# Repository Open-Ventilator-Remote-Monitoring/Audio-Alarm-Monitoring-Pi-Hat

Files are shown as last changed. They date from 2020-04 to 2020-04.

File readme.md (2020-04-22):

## Audio Alarm Monitoring Raspberry Pi Hat
### Overview
This add-on circuit board (Pi Hat) provides a 2.5mm audio input jack to allow a Soundear audio monitoring device to interface with a raspberry pi configured to work with the [Open Ventilator Remote Monitoring Software](https://github.com/Open-Ventilator-Remote-Monitoring/remote-ventilator-monitor-pi). An indicator LED is illuminated when a 5V digital signal is received from the Soundear audio monitor. This PCB contains a voltage divider circuit which reduces the 5V digital output from the soundear monitor to 3.3v digital logic suitable for the raspberry pi.

### Inputs & Outputs
#### Inputs
* 2.5mm audio jack from cable connected to soundear (5V digital input)
* 5V power from raspberry pi
* Ground on raspberry pi

#### Outputs
* GPIO 4 pin on raspberry pi (3.3V digital output)

#### Bill Of Materials
The Bill of Materials is in the [Audio Alarm Monitoring Pi Hat.csv](https://github.com/Open-Ventilator-Remote-Monitoring/Audio-Alarm-Monitoring-Pi-Hat/blob/master/Audio%20Alarm%20Monitoring%20Pi%20Hat.csv) file

#### Manufacturing Notes
* This board has slotted holes for all the J1 pads. 
* Milling data is in Audio Alarm Monitoring Pi Hat.GML

#### Assembly Notes
* XA1 is an optional connector for an external LED. Do not populate D1 if you plan to use it.
* This hat connects to a Raspberry Pi using two 10mm tall standoffs. A third 10mm standoff can be connected to the hat and will sit ontop of the Raspberry Pi to add additional support.

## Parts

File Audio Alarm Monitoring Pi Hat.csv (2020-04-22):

Part | Quantity | Value | Package | MFG Part Number | Link | Note | Library | Position | (mil) | Orientation
D1 | 1 |  | 1206 | QTLP651C4TR | https://www.digikey.com/product-detail/en/everlight-electronics-co-ltd/QTLP651C4TR/1080-1484-1-ND/7598723 | This or any other 1206 Green LED | SparkFun-LED | (375 825) |  | R0
J1 | 1 |  |  | 35RAPC4BHN2 | https://www.digikey.com/products/en?keywords=SC1459-ND |  | 35RAPC4BHN2 | (220 1712 | .59843) | R270
J2 | 1 |  | 2X6 FEMALE | BCS-106-L-D-TE | https://www.digikey.com/product-detail/en/samtec-inc/BCS-106-L-D-TE/SAM1008-06-ND/1100265 | This or any other 2x6 .1” connector | SparkFun-Connectors | -329.5275 | 6 2705.90551) | R0
Q1 | 1 |  | SOT-23 | MMSS8050-L-TP | https://www.digikey.com/product-detail/en/micro-commercial-co/MMSS8050-L-TP/MMSS8050-L-TPMSCT-ND/2827203 |  | SMD-TRANSISTORS-NPN-25V-500MW_SOT-23_ | (400 1025 | ) | R180
R1 | 1 | 2.2k | 1206 | CRG1206F2K2 | https://www.digikey.com/product-detail/en/te-connectivity-passive-product/CRG1206F2K2/A106075CT-ND/3477730 | This or any other 1206 resistor | SparkFun-Passives | (350 2450 | ) | R270
R2 | 1 | 3.3k | 1206 | CRG1206F3K3 | https://www.digikey.com/product-detail/en/te-connectivity-passive-product/CRG1206F3K3/A106076CT-ND/3477732 | This or any other 1206 resistor | SparkFun-Passives | (500 2450 | ) | R90
R3 | 1 | 4.7k | 1206 | CRG1206F4K7 | https://www.digikey.com/product-detail/en/te-connectivity-passive-product/CRG1206F4K7/A106078CT-ND/3477735 | This or any other 1206 resistor | SparkFun-Passives | (450 1250 | ) | R270
R4 | 1 | 150 | 1206 | RC1206FR-07150RL | https://www.digikey.com/product-detail/en/yageo/RC1206FR-07150RL/311-150FRCT-ND/731508 | This or any other 1206 resistor | SparkFun-Passives | (300 1250 | ) | R90
XA1 | 1 |  | XHP-2 | B2B-XH-A-GU | https://www.digikey.com/product-detail/en/jst-sales-america-inc/B2B-XH-A-GU/455-2946-ND/ | OPTIONAL | XHP-2 | (750 1100 | ) | R270
STANDOFF | 3 | M2.5x10 |  | 970100155 | https://www.digikey.com/product-detail/en/würth-elektronik/970100155/732-12993-ND/9488697 | 10mm Tall
BOLT | 6 | M2.5x6 |  | 91290A101 | https://www.mcmaster.com/91290a101

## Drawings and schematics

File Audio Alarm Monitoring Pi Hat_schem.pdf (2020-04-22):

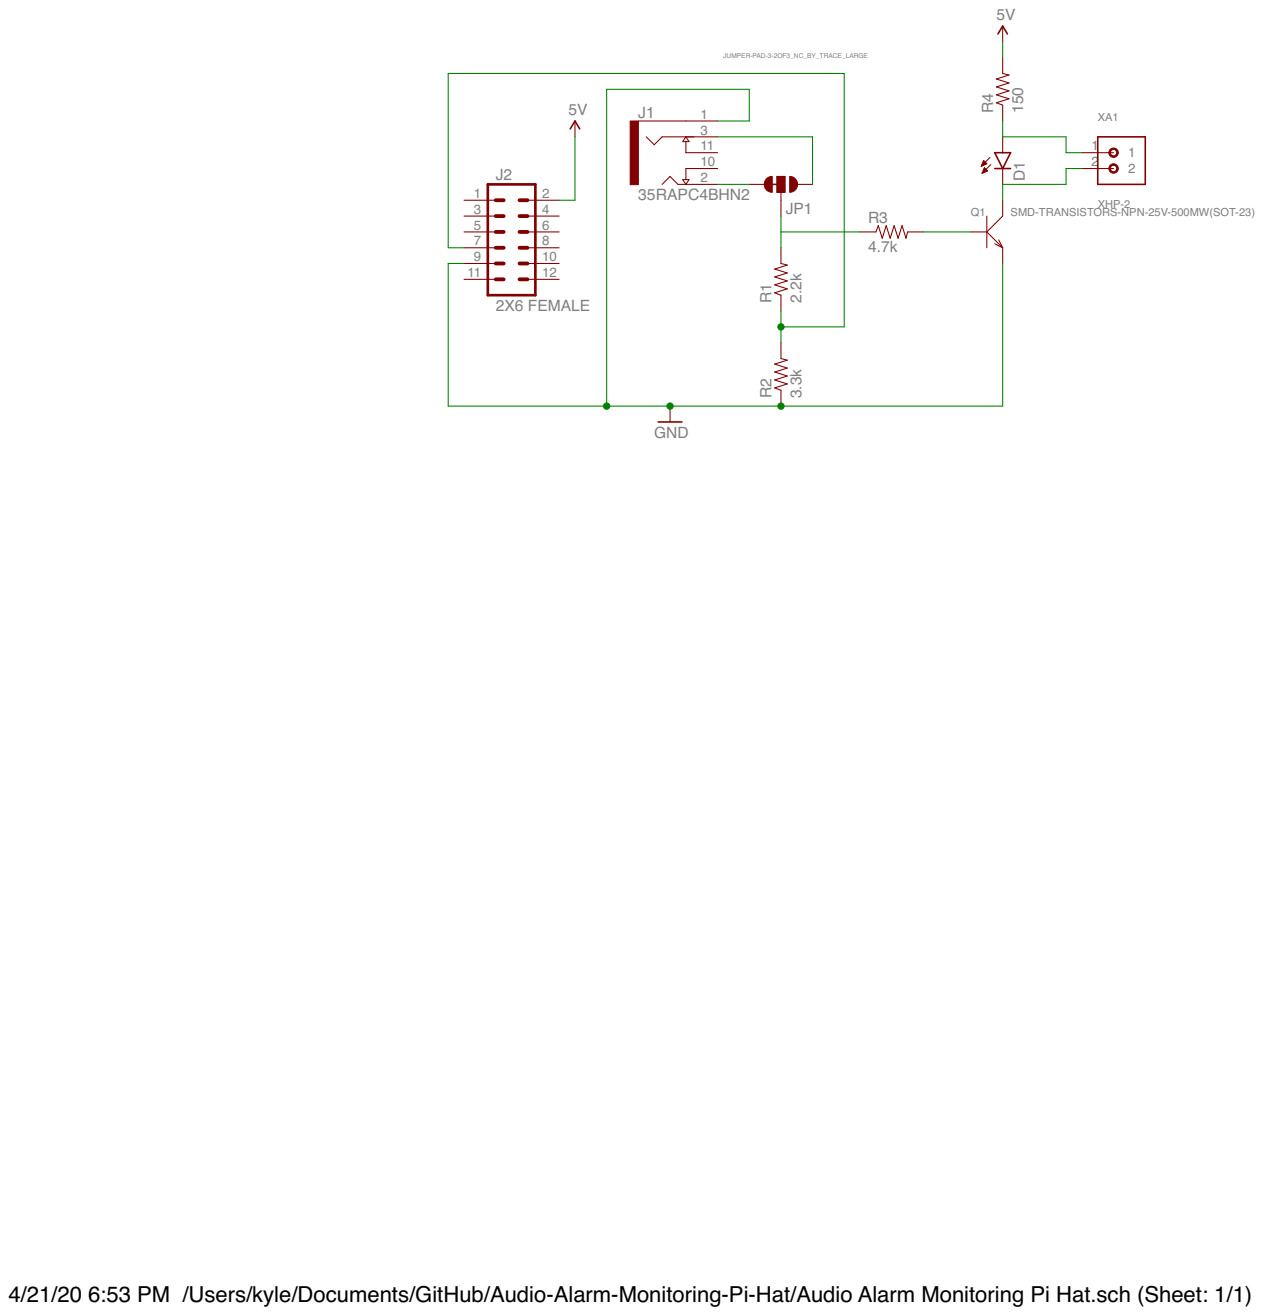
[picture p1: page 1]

SMD-TRANSISTORS-NPN-25V-500MW(SOT-23)

4/21/20 6:53 PM /Users/kyle/Documents/GitHub/Audio-Alarm-Monitoring-Pi-Hat/Audio Alarm Monitoring Pi Hat.sch (Sheet: 1/1)

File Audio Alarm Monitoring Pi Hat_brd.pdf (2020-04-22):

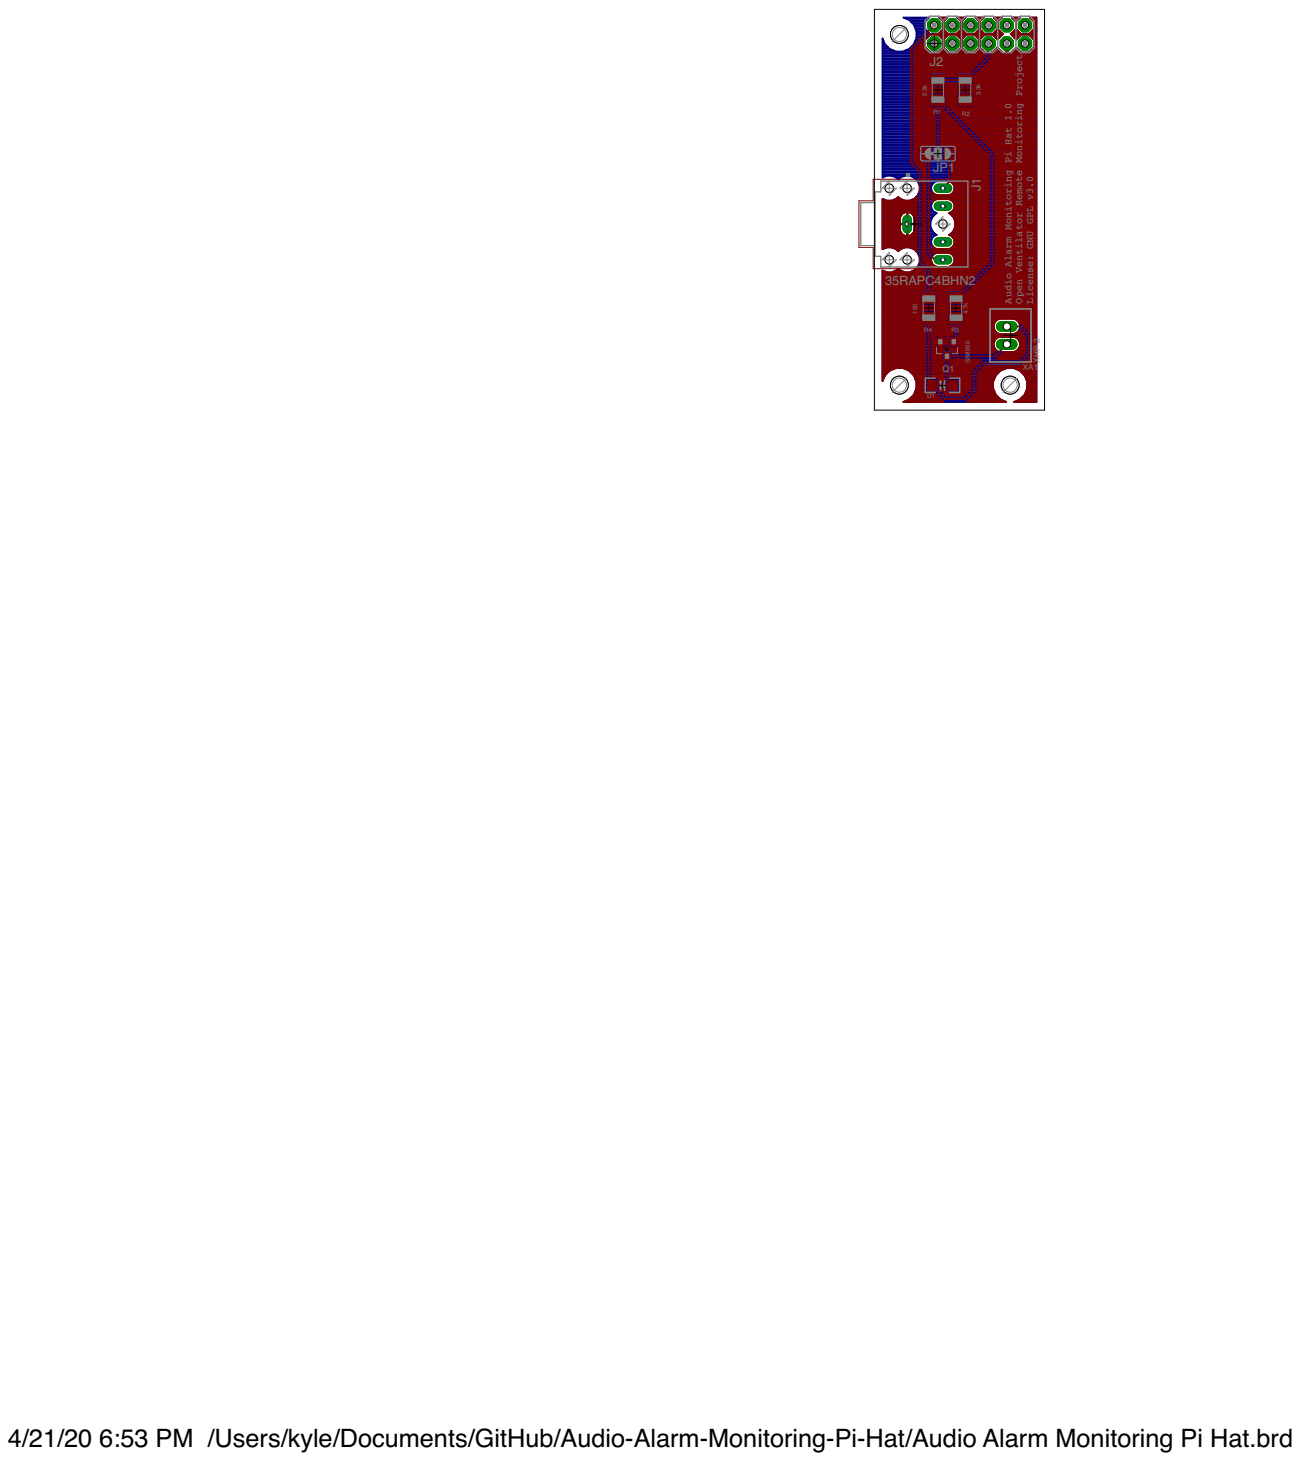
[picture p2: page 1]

Open Ventilator Remote Monitoring Project

Audio Alarm Monitoring Pi Hat 1.0

35RAPC4BHN2

4/21/20 6:53 PM /Users/kyle/Documents/GitHub/Audio-Alarm-Monitoring-Pi-Hat/Audio Alarm Monitoring Pi Hat.brd

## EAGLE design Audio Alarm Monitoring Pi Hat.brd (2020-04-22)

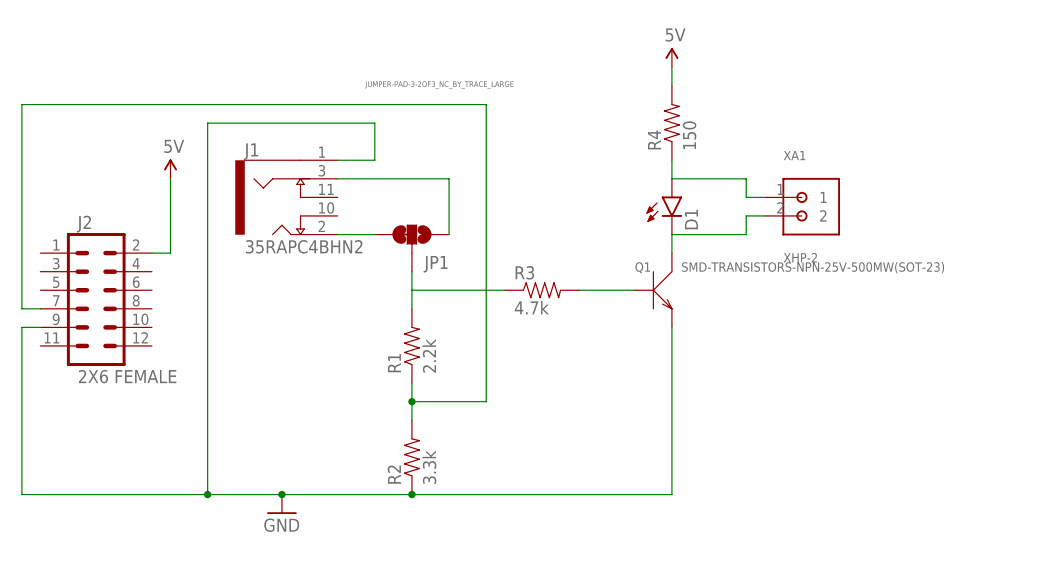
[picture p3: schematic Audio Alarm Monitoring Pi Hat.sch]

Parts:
D1: LED1206; LED-1206
J1: 35RAPC4BHN2; SWITCHCRAFT_35RAPC4BHN2
J2: 2X6 FEMALE; 2X6
JP1: JUMPER-PAD-3-2OF3_NC_BY_TRACE_LARGE; PAD-JUMPER-3-2OF3_NC_BY_TRACE_YES_SILK_LARGE
Q1: SMD-TRANSISTORS-NPN-25V-500MW(SOT-23); SOT-23
R1: 2.2k; 1206
R2: 3.3k; 1206
R3: 4.7k; 1206
R4: 150; 1206
XA1: XHP-2; JST_XHP-2

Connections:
5V: J2.2, R4.2
GND: J1.1, J2.9, Q1.2 (E), R2.1
unnamed: J2.7, R1.1, R2.2
unnamed: JP1.2, R1.2, R3.1
unnamed: J1.2, JP1.3
unnamed: D1.C, Q1.3 (C), XA1.2
unnamed: J1.3, JP1.1
unnamed: D1.A, R4.1, XA1.1
unnamed: Q1.1 (B), R3.2

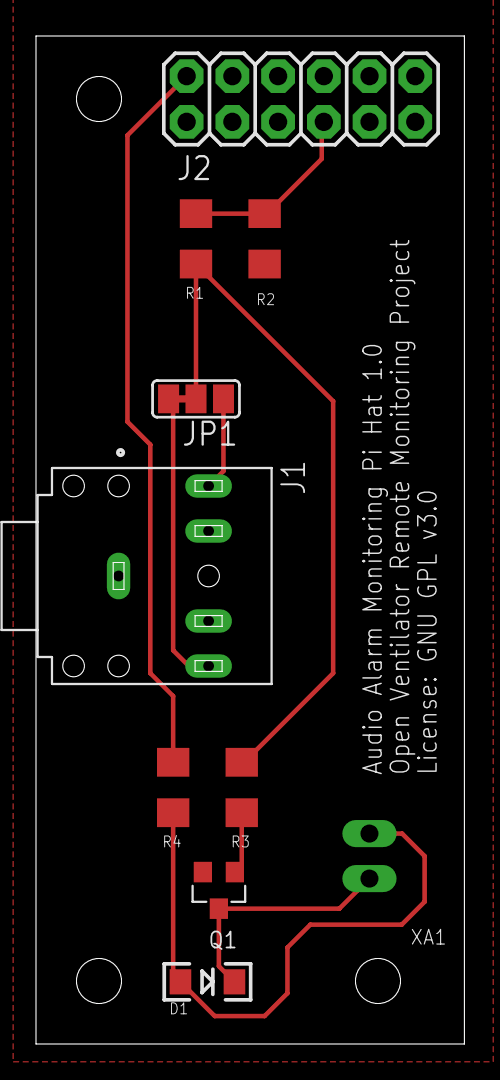
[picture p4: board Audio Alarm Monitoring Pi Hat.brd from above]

Board: 2 copper layers, 23.8 x 56.0 mm, 10 parts (0 on the bottom side), 9 nets.

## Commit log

2020-04-22 Board with SMD and through hole parts
    [ovhat.GBL, ovhat.GBO, ovhat.GBS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]
2020-04-22 Name Change
    [Audio Alarm Monitoring Pi Hat.brd, Audio Alarm Monitoring Pi Hat.sch]
2020-04-22 Updating for LED + all surface mount resistors
    [Audio Alarm Monitoring Pi Hat.GBL, Audio Alarm Monitoring Pi Hat.GBO, Audio Alarm Monitoring Pi Hat.GBS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]
2020-04-22 Added values layer to top sillscreen
    [Audio Alarm Monitoring Pi Hat.GTO]
2020-04-22 BOM + readme update
    [Audio Alarm Monitoring Pi Hat.csv]
2020-04-22 Update readme with board image

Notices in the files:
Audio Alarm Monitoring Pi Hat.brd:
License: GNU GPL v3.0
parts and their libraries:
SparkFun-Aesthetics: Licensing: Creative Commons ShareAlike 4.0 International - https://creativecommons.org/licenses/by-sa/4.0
